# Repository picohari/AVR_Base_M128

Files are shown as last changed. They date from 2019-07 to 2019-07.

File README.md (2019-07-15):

# AVR ATmega128 development board

Simple board with ATmega128 microcontroller and breakout connectors for each port

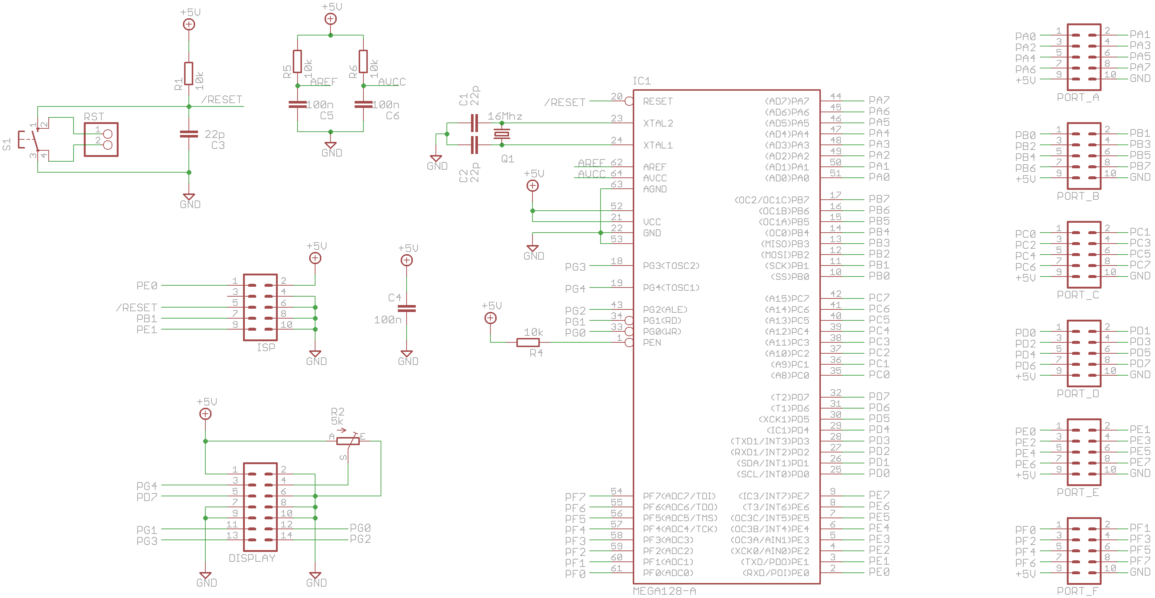
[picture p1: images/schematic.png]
ATmega base schematic


## Hardware:

* Each port is accessible over Molex 10pin header (Px0 - Px7, +5V, GND)
* L7805 voltage regulator
* Serial driver ic for 2x RS-232
* LCD connector for HD44780 displays (no BUSY reading possible, just wait..)
* Pinheader for display background LED
* Reset button
* 16 MHz crystal oscillator
* Additional +5V and GND pins
* Holes for easy mounting

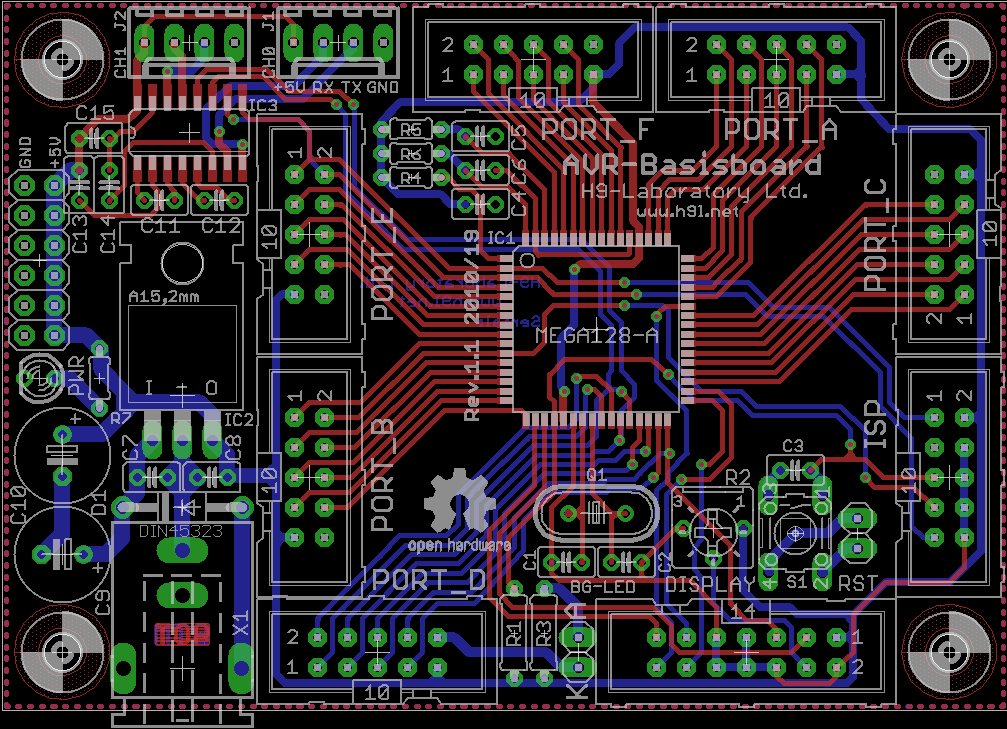
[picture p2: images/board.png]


## Software:

Check out my other GitHub pages for more driver support (only C), I will post some libraries once I've got more time...

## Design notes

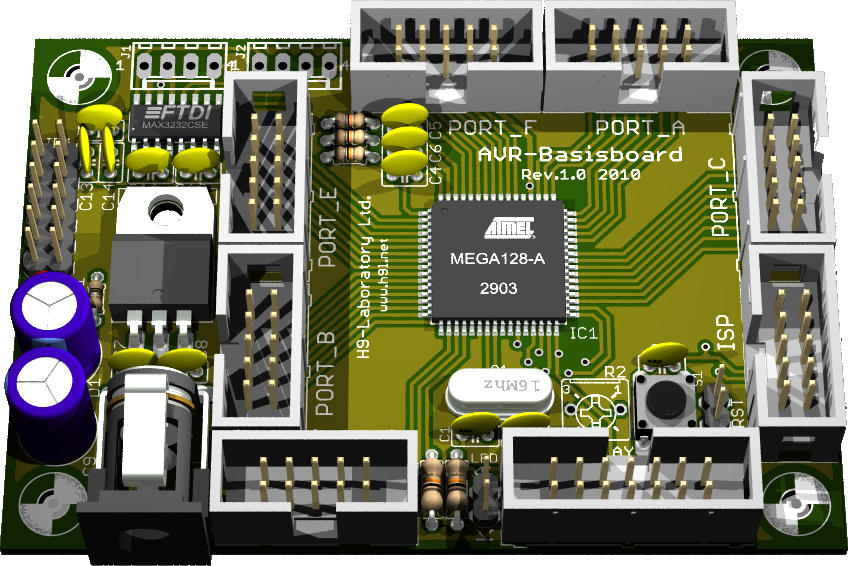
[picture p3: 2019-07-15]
images/pcb-avr_base.jpg

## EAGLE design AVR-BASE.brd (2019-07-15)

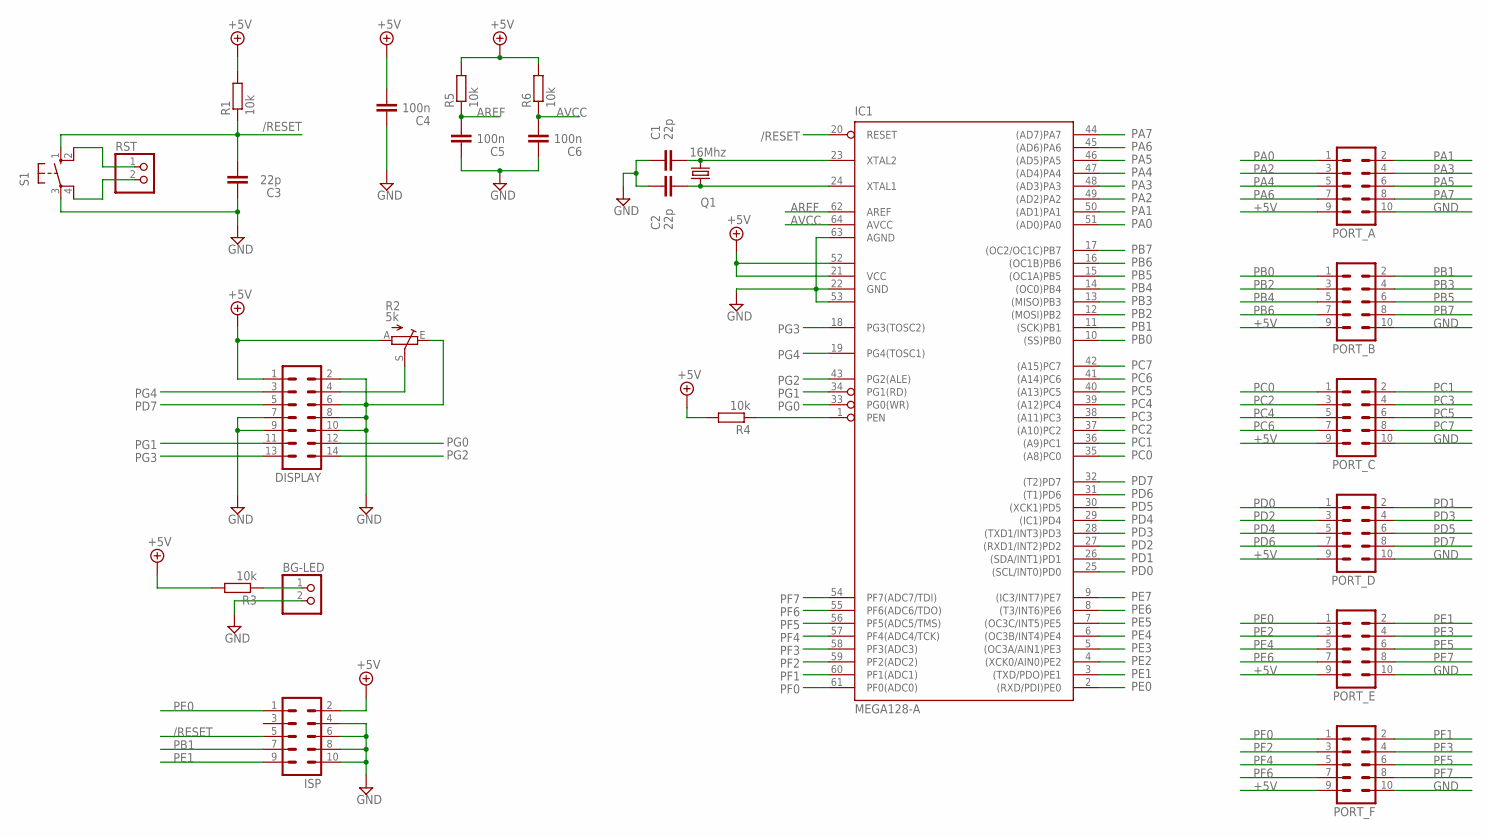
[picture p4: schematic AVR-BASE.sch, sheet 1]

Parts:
BG-LED: PINHD-1X2; 1X02
C1, C2, C3: 22p; C025-025X050
C4, C5, C6: 100n; C025-025X050
DISPLAY: ML14
IC1: MEGA128-A; TQFP64
ISP: ML10
PORT_A: ML10
PORT_B: ML10
PORT_C: ML10
PORT_D: ML10
PORT_E: ML10
PORT_F: ML10
Q1: 16Mhz; HC49U-V
R1, R3: 10k; 0207/7
R2: 5k; B25P
R4, R5, R6: 10k; 0204/5
RST: PINHD-1X2; 1X02
S1: 10-XX; B3F-10XX

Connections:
+5V: C4.2, DISPLAY.1, IC1.21 (VCC), IC1.52 (VCC1), ISP.2, PORT_A.9, PORT_B.9, PORT_C.9, PORT_D.9, PORT_E.9, PORT_F.9, R1.2, R2.A, R3.2, R4.2, R5.2, R6.2; also elsewhere on the board
/RESET: C3.2, IC1.20 (RESET), ISP.5, R1.1, S1.1 (S)
AREF: C5.2, IC1.62 (AREF), R5.1
AVCC: C6.2, IC1.64 (AVCC), R6.1
GND: BG-LED.2, C1.1, C2.1, C3.1, C4.1, C5.1, C6.1, DISPLAY.2, DISPLAY.6, DISPLAY.7, DISPLAY.8, DISPLAY.9, DISPLAY.10, IC1.22 (GND), IC1.53 (GND1), IC1.63 (AGND), ISP.4, ISP.6, ISP.8, ISP.10, PORT_A.10, PORT_B.10, PORT_C.10, PORT_D.10, PORT_E.10, PORT_F.10, R2.E, S1.3; also elsewhere on the board
unnamed: C1.2, IC1.23 (XTAL2), Q1.2
unnamed: C2.2, IC1.24 (XTAL1), Q1.1
unnamed: RST.1, S1.2 (S1)
unnamed: DISPLAY.4, R2.S
unnamed: RST.2, S1.4 (P1)
unnamed: IC1.1 (PEN), R4.1
unnamed: BG-LED.1, R3.1
PA0: IC1.51 ((AD0)PA0), PORT_A.1
PA1: IC1.50 ((AD1)PA1), PORT_A.2
PA2: IC1.49 ((AD2)PA2), PORT_A.3
PA3: IC1.48 ((AD3)PA3), PORT_A.4
PA4: IC1.47 ((AD4)PA4), PORT_A.5
PA5: IC1.46 ((AD5)PA5), PORT_A.6
PA6: IC1.45 ((AD6)PA6), PORT_A.7
PA7: IC1.44 ((AD7)PA7), PORT_A.8
PB0: IC1.10 ((SS)PB0), PORT_B.1
PB1: IC1.11 ((SCK)PB1), ISP.7, PORT_B.2
PB2: IC1.12 ((MOSI)PB2), PORT_B.3
PB3: IC1.13 ((MISO)PB3), PORT_B.4
PB4: IC1.14 ((OC0)PB4), PORT_B.5
PB5: IC1.15 ((OC1A)PB5), PORT_B.6
PB6: IC1.16 ((OC1B)PB6), PORT_B.7
PB7: IC1.17 ((OC2/OC1C)PB7), PORT_B.8
PC0: IC1.35 ((A8)PC0), PORT_C.1
PC1: IC1.36 ((A9)PC1), PORT_C.2
PC2: IC1.37 ((A10)PC2), PORT_C.3
PC3: IC1.38 ((A11)PC3), PORT_C.4
PC4: IC1.39 ((A12)PC4), PORT_C.5
PC5: IC1.40 ((A13)PC5), PORT_C.6
PC6: IC1.41 ((A14)PC6), PORT_C.7
PC7: IC1.42 ((A15)PC7), PORT_C.8
PD0: IC1.25 ((SCL/INT0)PD0), PORT_D.1
PD1: IC1.26 ((SDA/INT1)PD1), PORT_D.2
PD2: IC1.27 ((RXD1/INT2)PD2), PORT_D.3; also elsewhere on the board
PD3: IC1.28 ((TXD1/INT3)PD3), PORT_D.4; also elsewhere on the board
PD4: IC1.29 ((IC1)PD4), PORT_D.5
PD5: IC1.30 ((XCK1)PD5), PORT_D.6
PD6: IC1.31 ((T1)PD6), PORT_D.7
PD7: DISPLAY.5, IC1.32 ((T2)PD7), PORT_D.8
PE0: IC1.2 ((RXD/PDI)PE0), ISP.1, PORT_E.1; also elsewhere on the board
PE1: IC1.3 ((TXD/PDO)PE1), ISP.9, PORT_E.2; also elsewhere on the board
PE2: IC1.4 ((XCK0/AIN0)PE2), PORT_E.3
PE3: IC1.5 ((OC3A/AIN1)PE3), PORT_E.4
PE4: IC1.6 ((OC3B/INT4)PE4), PORT_E.5
PE5: IC1.7 ((OC3C/INT5)PE5), PORT_E.6
PE6: IC1.8 ((T3/INT6)PE6), PORT_E.7
PE7: IC1.9 ((IC3/INT7)PE7), PORT_E.8
PF0: IC1.61 (PF0(ADC0)), PORT_F.1
PF1: IC1.60 (PF1(ADC1)), PORT_F.2
PF2: IC1.59 (PF2(ADC2)), PORT_F.3
PF3: IC1.58 (PF3(ADC3)), PORT_F.4
PF4: IC1.57 (PF4(ADC4/TCK)), PORT_F.5
PF5: IC1.56 (PF5(ADC5/TMS)), PORT_F.6
PF6: IC1.55 (PF6(ADC6/TDO)), PORT_F.7
PF7: IC1.54 (PF7(ADC7/TDI)), PORT_F.8
PG0: DISPLAY.12, IC1.33 (PG0(WR))
PG1: DISPLAY.11, IC1.34 (PG1(RD))
PG2: DISPLAY.14, IC1.43 (PG2(ALE))
PG3: DISPLAY.13, IC1.18 (PG3(TOSC2))
PG4: DISPLAY.3, IC1.19 (PG4(TOSC1))

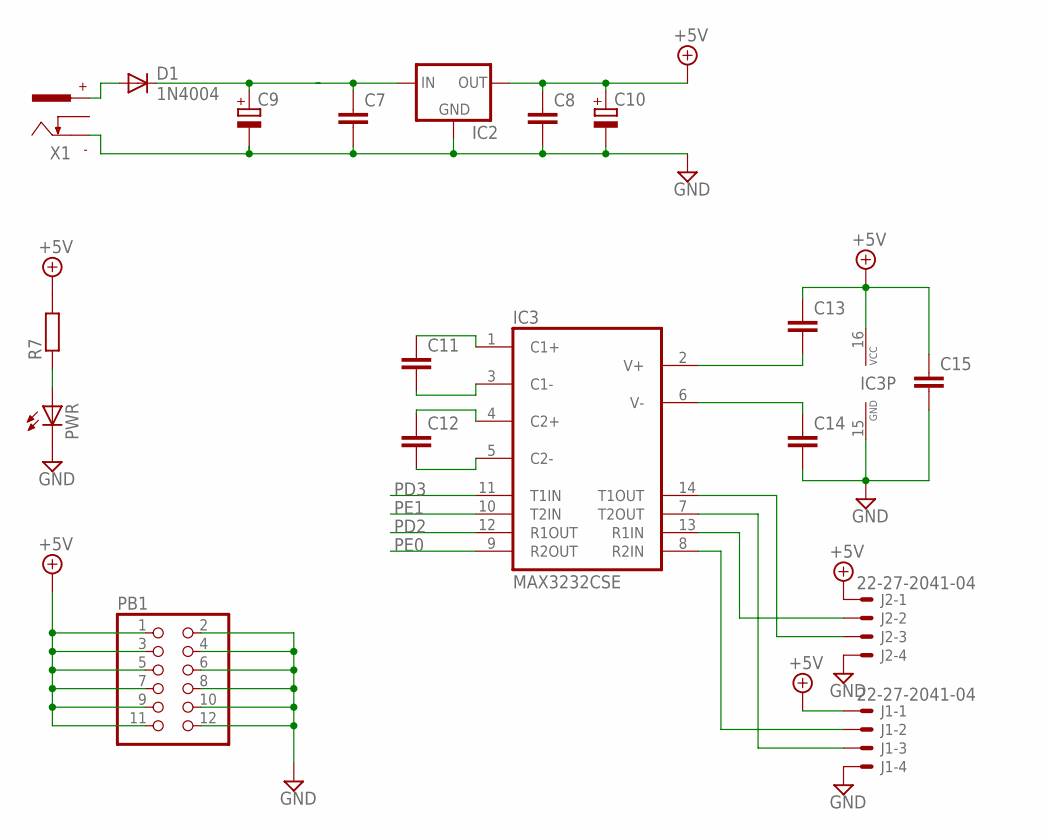
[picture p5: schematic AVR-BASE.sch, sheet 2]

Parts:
C7, C8, C11, C12, C13, C14, C15: C-EU025-025X050; C025-025X050
C9, C10: CPOL-EUE3.5-8; E3,5-8
D1: 1N4004; DO41-10
IC2: 78XXL
IC3: MAX3232CSE; SO16
J1, J2: 22-27-2041-04; 6410-04
PB1: PINHD-2X6; 2X06
PWR: LED3MM
R7: R-EU_0204/5; 0204/5
X1: 737992-55; 737992-5

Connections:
+5V: C8.1, C10.+, C13.1, C15.1, IC2.OUT, IC3.16 (VCC), J1.1, J2.1, PB1.1, PB1.3, PB1.5, PB1.7, PB1.9, PB1.11, R7.2; also elsewhere on the board
GND: C7.2, C8.2, C9.-, C10.-, C14.2, C15.2, IC2.GND, IC3.15 (GND), J1.4, J2.4, PB1.2, PB1.4, PB1.6, PB1.8, PB1.10, PB1.12, PWR.K (C), X1.+; also elsewhere on the board
unnamed: C7.1, C9.+, D1.C, IC2.IN
unnamed: D1.A, X1.-1
unnamed: PWR.A, R7.1
unnamed: C11.1, IC3.1 (C1+)
unnamed: C11.2, IC3.3 (C1-)
unnamed: C12.1, IC3.4 (C2+)
unnamed: C12.2, IC3.5 (C2-)
unnamed: C13.2, IC3.2 (V+)
unnamed: C14.1, IC3.6 (V-)
PD2: IC3.12 (R1OUT); also elsewhere on the board
PD3: IC3.11 (T1IN); also elsewhere on the board
PE0: IC3.9 (R2OUT); also elsewhere on the board
PE1: IC3.10 (T2IN); also elsewhere on the board
RX0: IC3.8 (R2IN), J1.2
RX1: IC3.13 (R1IN), J2.2
TX0: IC3.7 (T2OUT), J1.3
TX1: IC3.14 (T1OUT), J2.3

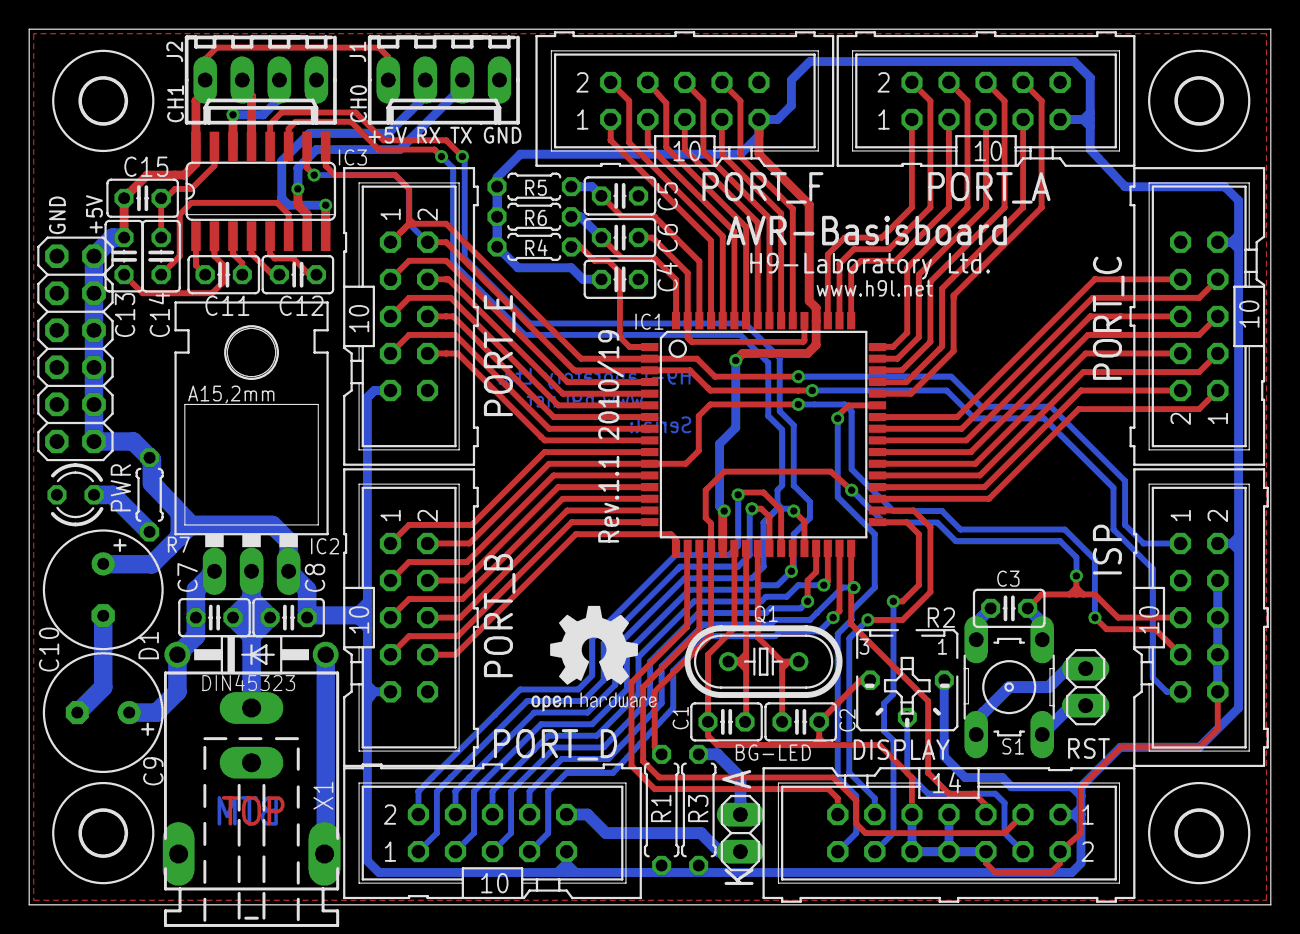
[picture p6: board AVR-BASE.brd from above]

Board: 2 copper layers, 85.1 x 60.0 mm, 47 parts (0 on the bottom side), 78 nets.

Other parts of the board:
U$1, U$2, U$3, U$4: 3,0
